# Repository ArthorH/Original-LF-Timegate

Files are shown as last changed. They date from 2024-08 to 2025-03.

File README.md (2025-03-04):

da
## Project Status: **Finished**  
**Design** ✅ — **Fabrication** ✅ — **Assembly** ✅ — **Bringup** ✅ — **Testing** ✅  
## Key technologies:
&nbsp;&nbsp;&nbsp;&nbsp; &nbsp;&nbsp;&nbsp;&nbsp;
## What is it?
LF-Timegate is a time measurement device developed to assist with Line Follower and Line Follower Drag competitions during the [XV ROBOTIC ARENA](https://roboticarena.pl/). It features circuit lap measurements and sprint measurements in one package with ±1ms accuracy.

rect22-7

### Measurement modes:



For more information, read the [setup guide](https://github.com/ArthorH/LF-Timegate-REVA/blob/main/LF-Timegate-Setup-Guide.pdf).

## What MCU does it use?
None.



To ensure reliability and simplicity, it utilizes 10 CMOS 4000 ICs to make all the magic happen.  

Also check out new drop in replacement [sensors](https://github.com/ArthorH/Simple-IR-Light-barrier) 
## Device in action:
[In this video](https://www.youtube.com/watch?v=xdkL_AgzkSc)

&nbsp;&nbsp;&nbsp;&nbsp; &nbsp;&nbsp;&nbsp;&nbsp; 
&nbsp;&nbsp;&nbsp;&nbsp; &nbsp;&nbsp;&nbsp;&nbsp; 
&nbsp;&nbsp;&nbsp;&nbsp; &nbsp;&nbsp;&nbsp;&nbsp; 
## Caution:
It is not recommended to manufacture this version (REV A) as it has 10 errors on the PCB. They are fairly simple and fixable as shown here:

#### Error in state machine 
&nbsp;&nbsp;&nbsp;&nbsp; &nbsp;&nbsp;&nbsp;&nbsp; 
&nbsp;&nbsp;&nbsp;&nbsp; &nbsp;&nbsp;&nbsp;&nbsp; 
&nbsp;&nbsp;&nbsp;&nbsp; &nbsp;&nbsp;&nbsp;&nbsp; 

## Authors
[Artem Horiunov](https://github.com/ArthorH) - schematic (state machine) and layout

[Dominik Pluta](https://github.com/Dominik-Workshop) - ir receivers and schematic

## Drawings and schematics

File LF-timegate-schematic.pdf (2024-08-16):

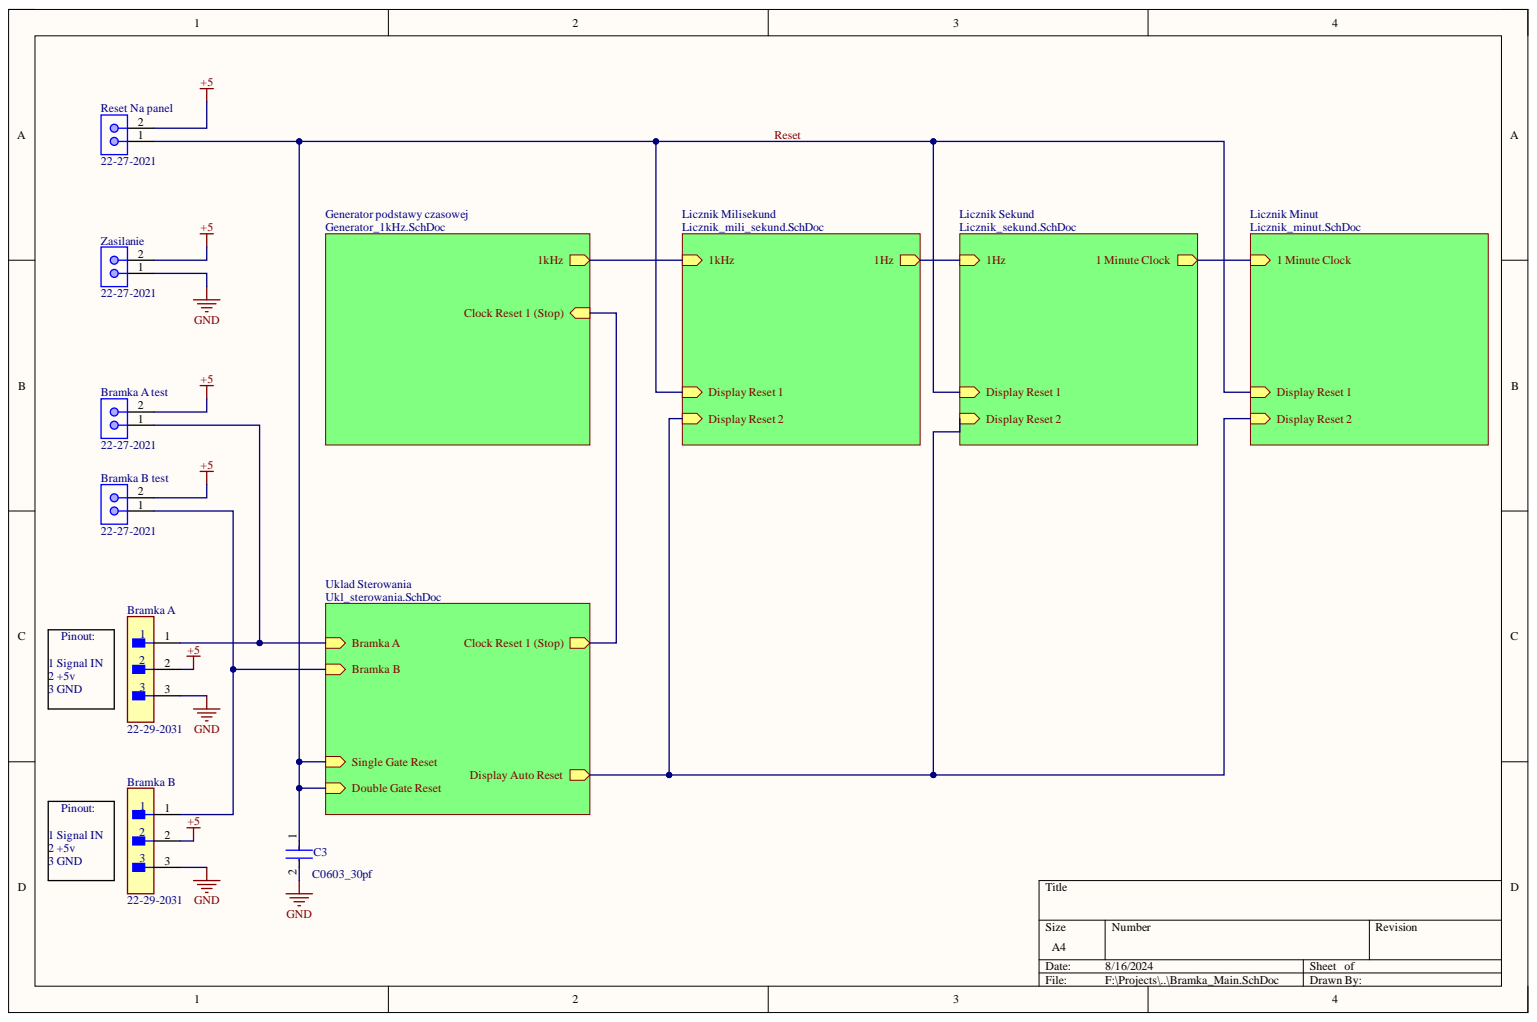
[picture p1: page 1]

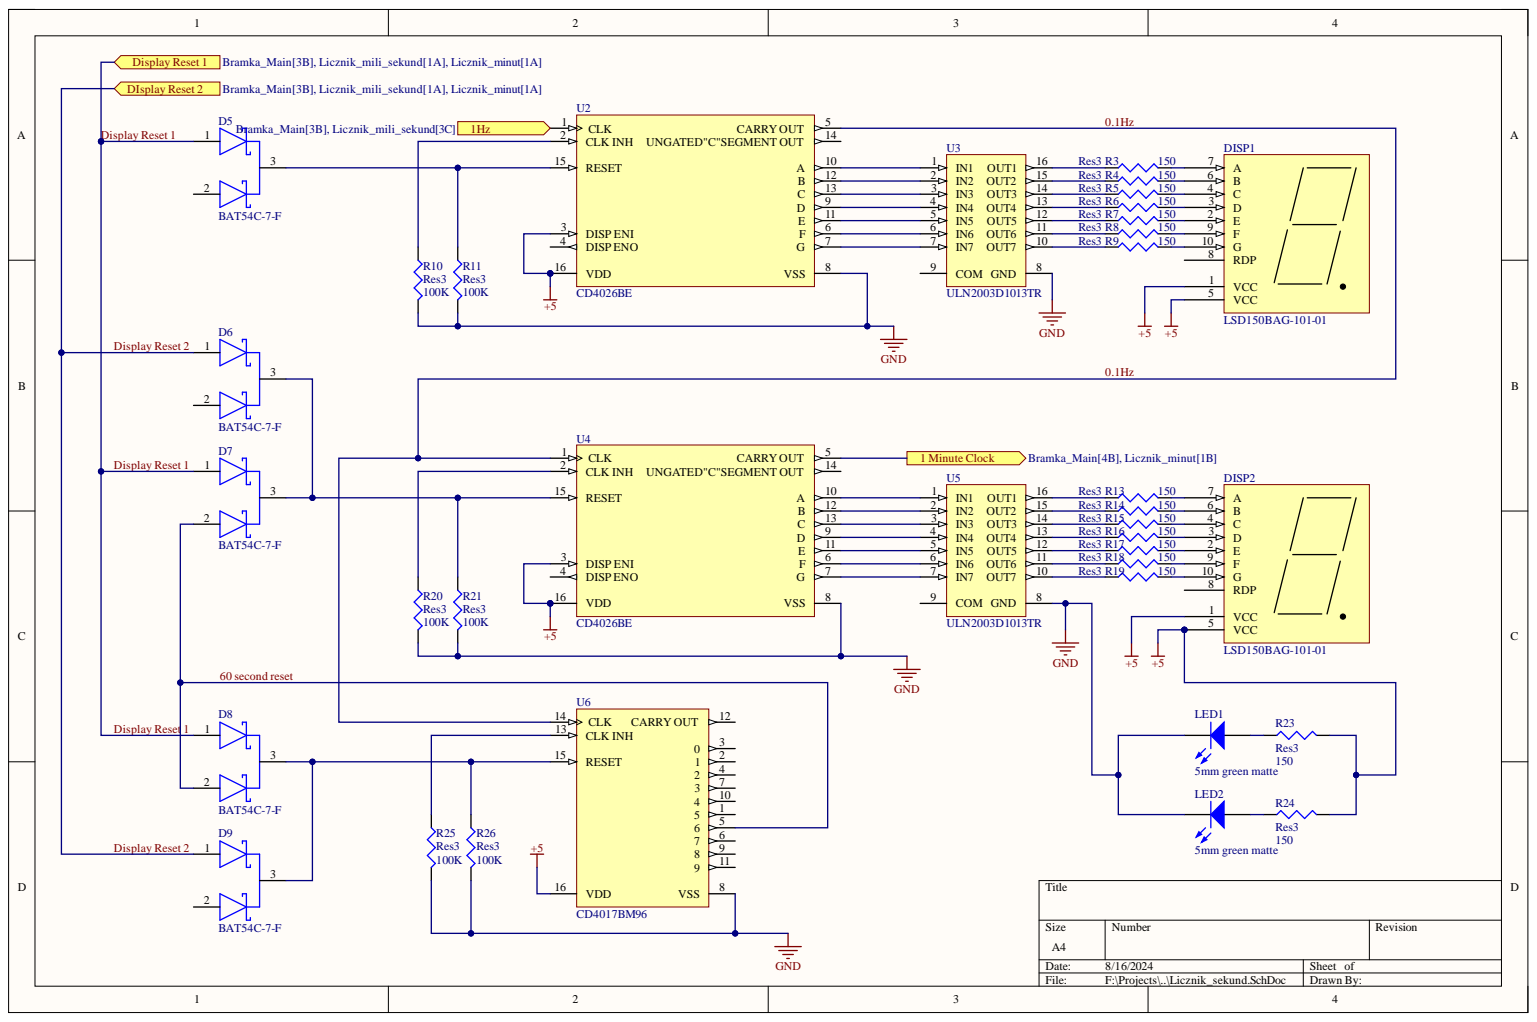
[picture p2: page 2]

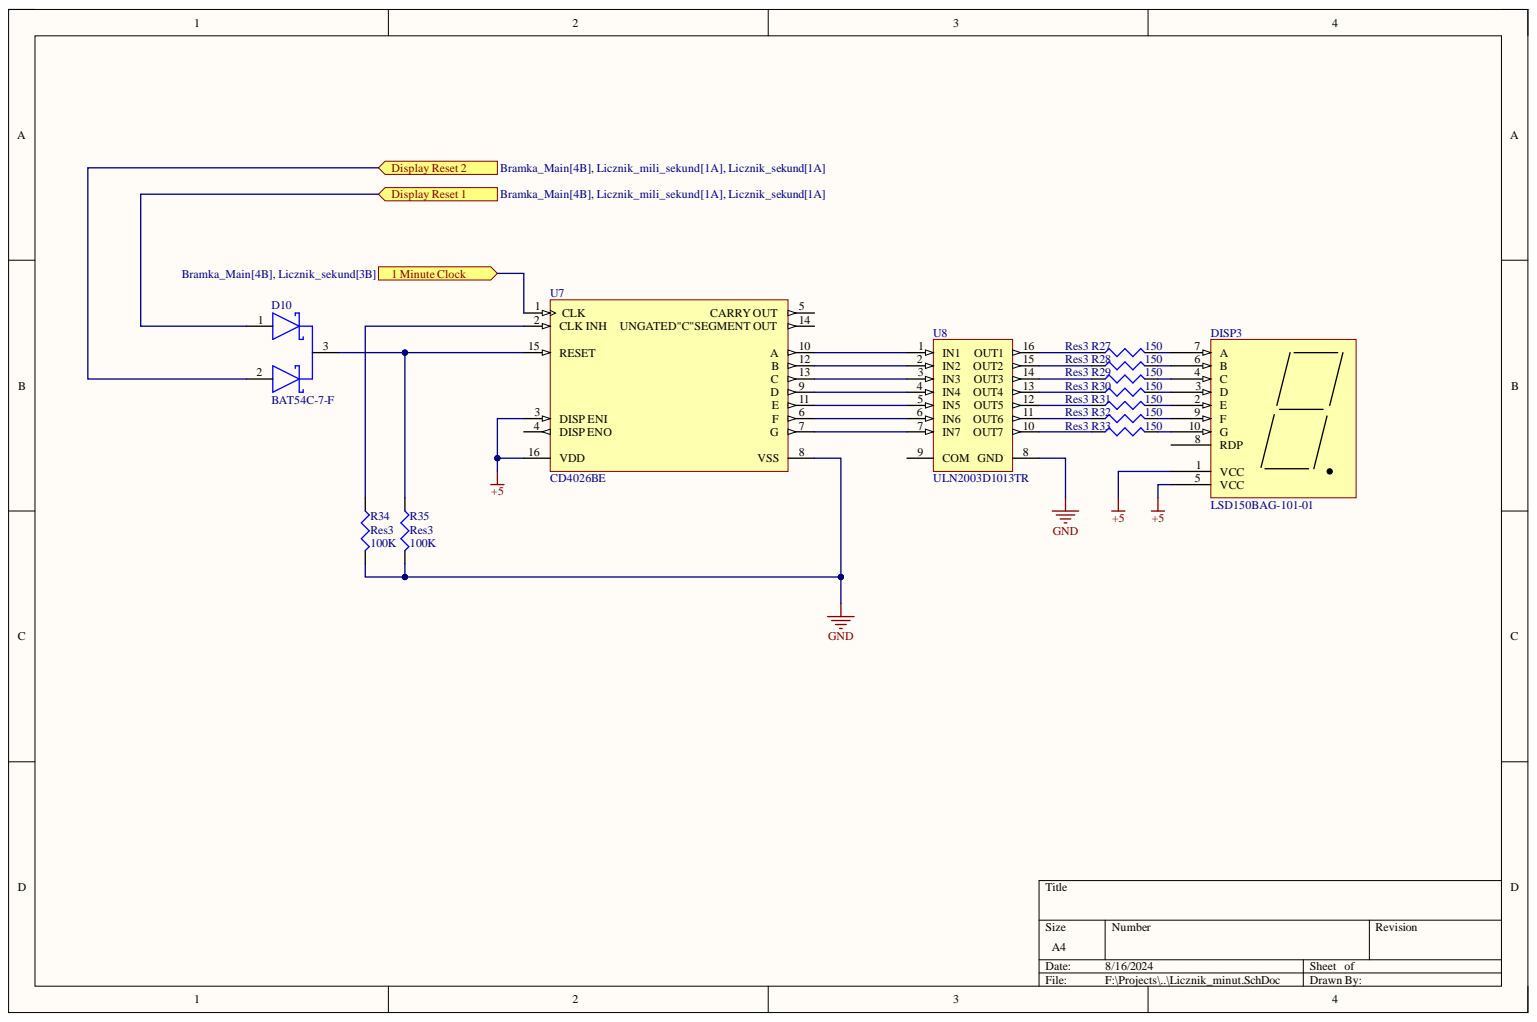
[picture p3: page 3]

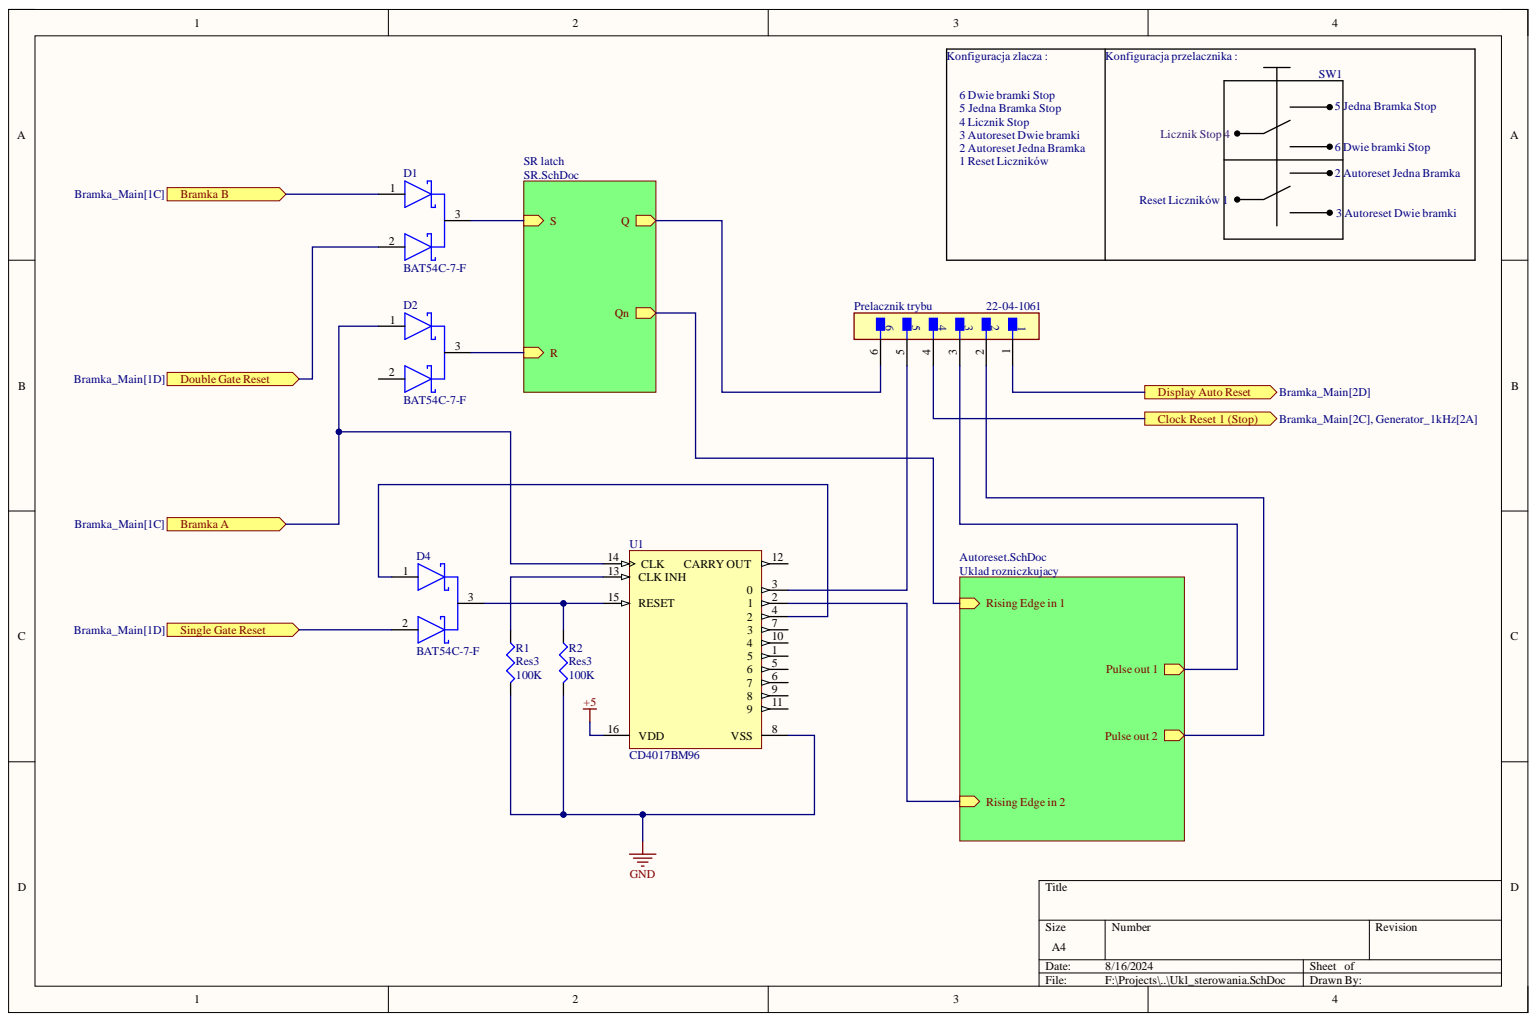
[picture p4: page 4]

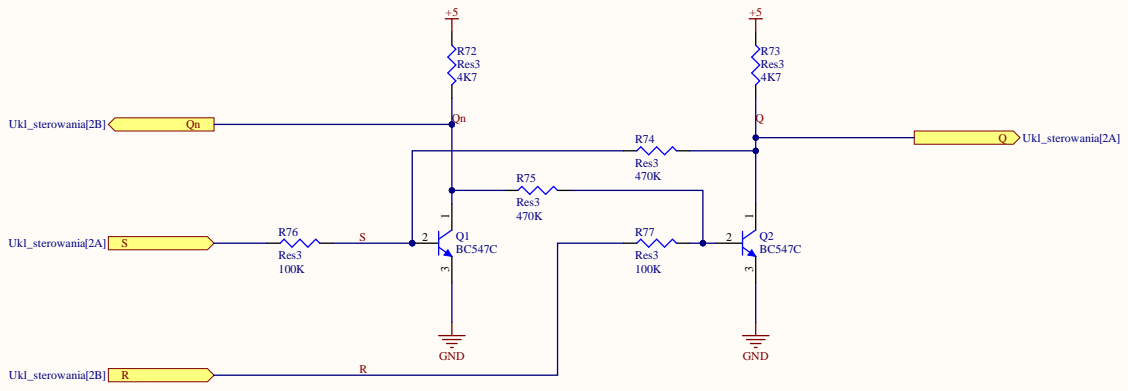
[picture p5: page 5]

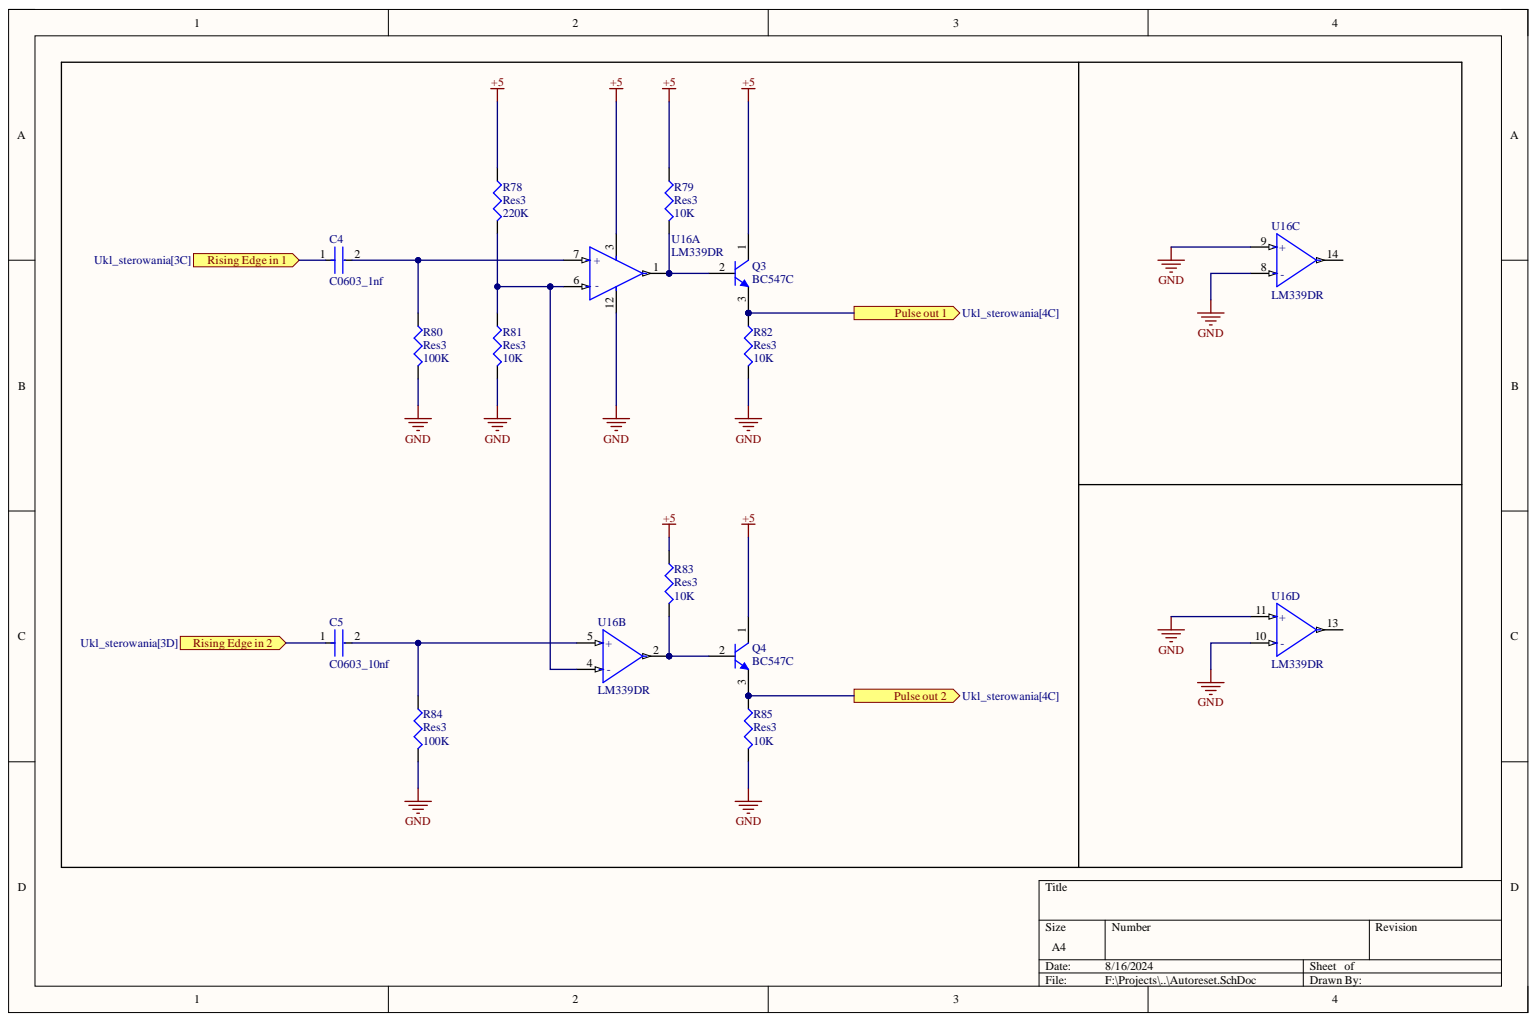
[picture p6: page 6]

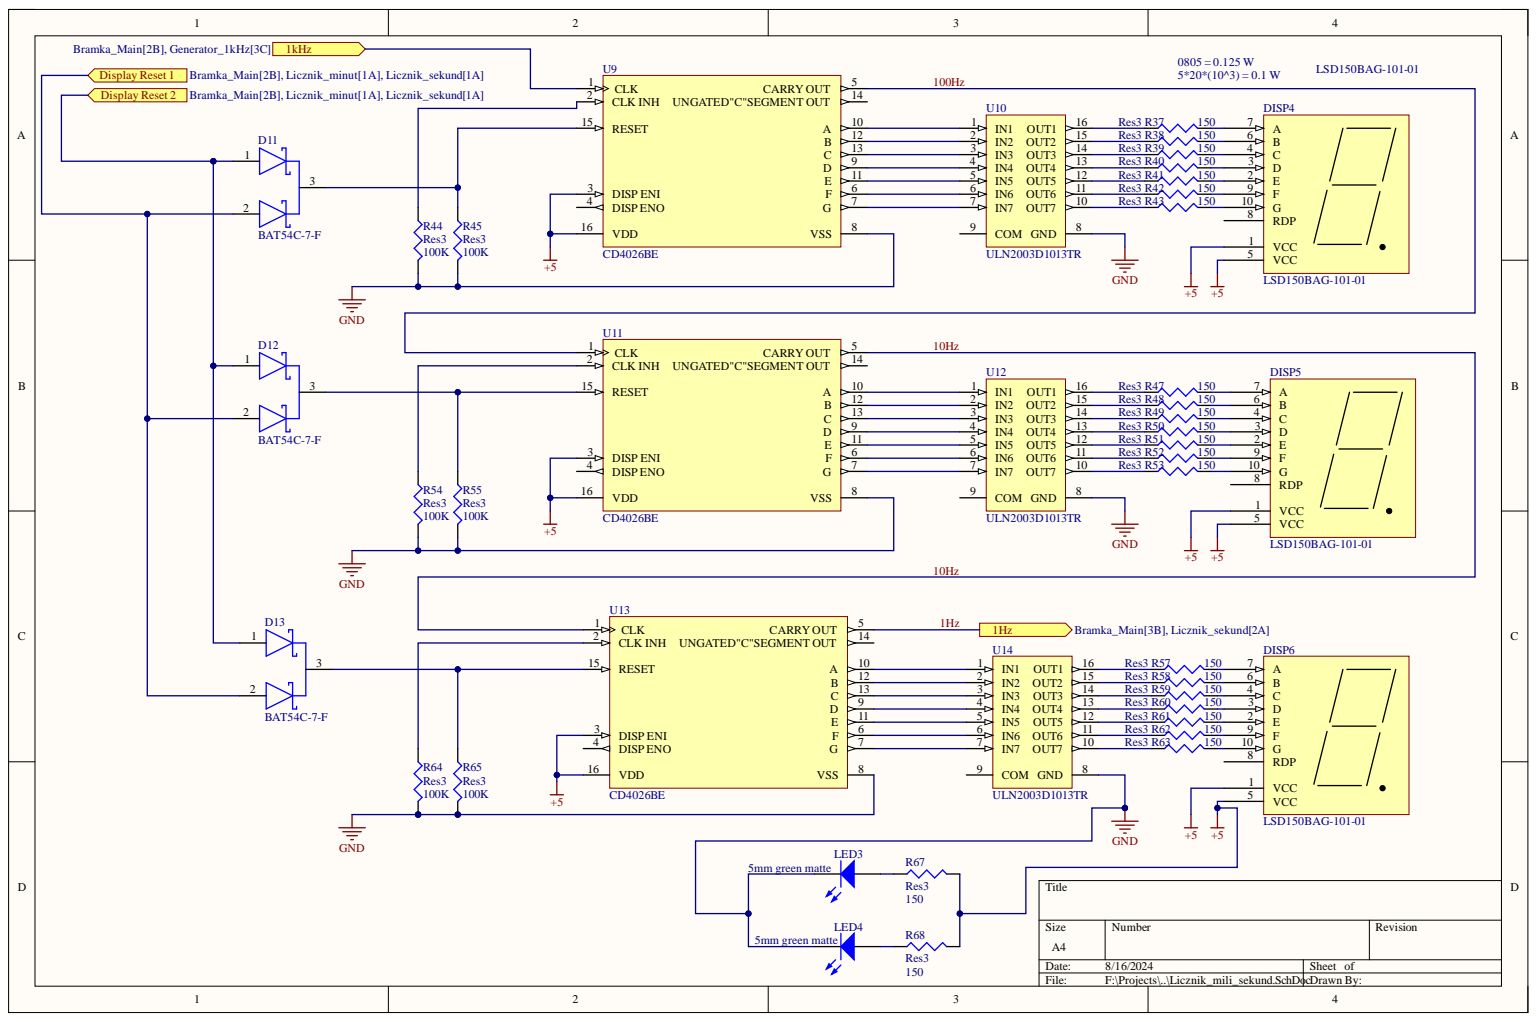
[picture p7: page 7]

VDD 16

VCC 5

VDD 16 | 10Hz

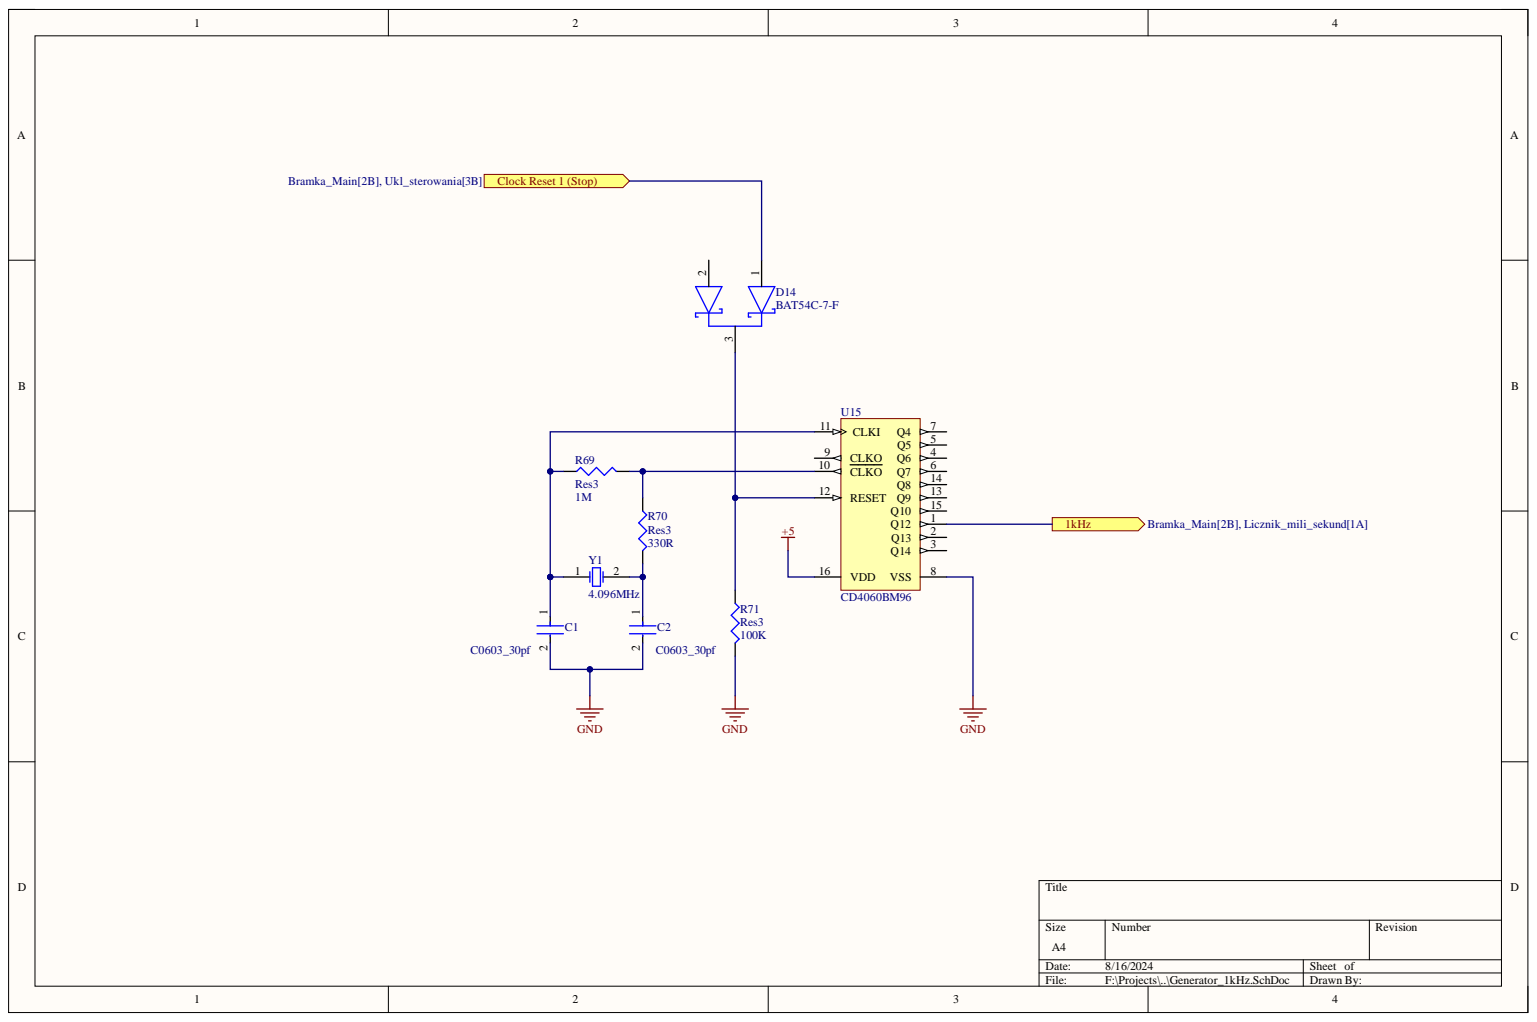
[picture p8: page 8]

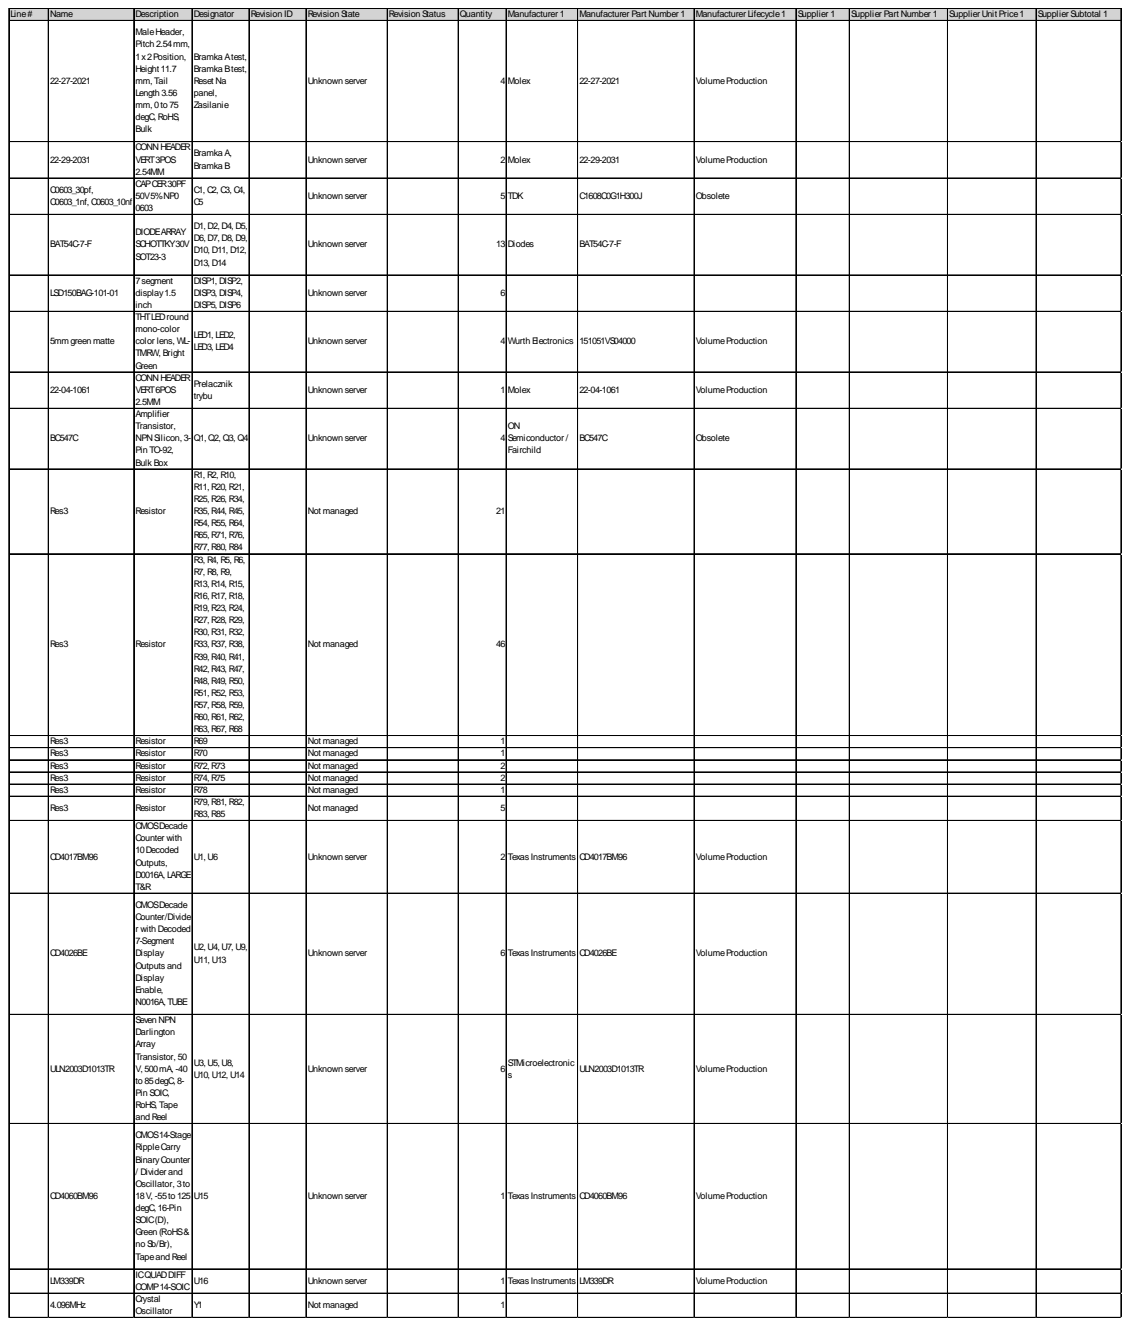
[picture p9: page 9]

Line# | Name | Description | Designator | Revision ID | Revision State | Revision Status | Quantity | Manufacturer 1 | Manufacturer Part Number 1 | Manufacturer Lifecycle1 | Supplier 1 | Supplier Part Number 1 | Supplier Unit Price1 | Supplier Subtotal 1

22-27-2021 | MaleHeader, Pitch 2.54mm, 1x2Position, Height 11.7 mm, Tail Length 3.56 mm, 0to 75 degC, RoHS, Bulk | Bramka Atest, Bramka Btest, Reset Na panel, Zasilanie | | Unknown server | | 4 Molex | | 22-27-2021 | VolumeProduction

22-29-2031 | CONN HEADER VERT3POS 2.54MM | Bramka A, Bramka B | | Unknown server | | 2 Molex | | 22-29-2031 | VolumeProduction

C0603_30pf, C0603_1nf, C0603_10nf | CAPCER30PF 50V5%NP0 0603 | C1, C2, C3, C4, C5 | | Unknown server | | 5 TDK | | C1608C0G1H300J | Obsolete

BAT54C-7-F | DIODEARRAY SCHOTTKY30V SOT23-3 | D1, D2, D4, D5, D6, D7, D8, D9, D10, D11, D12, D13, D14 | | Unknown server | | 13 Diodes | | BAT54C-7-F

LSD150BAG-101-01 | 7segment display1.5 inch | DISP1, DISP2, DISP3, DISP4, DISP5, DISP6 | | Unknown server | | 6

5mm green matte | THTLEDround mono-color color lens, WL-TMRW, Bright Green | LED1, LED2, LED3, LED4 | | Unknown server | | 4 Wurth Electronics | | 151051VS04000 | VolumeProduction

22-04-1061 | CONN HEADER VERT6POS 2.5MM | Prelacznik trybu | | Unknown server | | 1 Molex | | 22-04-1061 | VolumeProduction

BC547C | Amplifier Transistor, NPN Silicon, 3-Pin TO-92, BulkBox | Q1, Q2, Q3, Q4 | | Unknown server | | 4 | ON Semiconductor / Fairchild | BC547C | Obsolete

Res3 | Resistor | R1, R2, R10, R11, R20, R21, R25, R26, R34, R35, R44, R45, R54, R55, R64, R65, R71, R76, R77, R80, R84 | | Not managed | | 21

Res3 | Resistor | R3, R4, R5, R6, R7, R8, R9, R13, R14, R15, R16, R17, R18, R19, R23, R24, R27, R28, R29, R30, R31, R32, R33, R37, R38, R39, R40, R41, R42, R43, R47, R48, R49, R50, R51, R52, R53, R57, R58, R59, R60, R61, R62, R63, R67, R68 | | Not managed | | 46

Res3 | Resistor | R69 | | Not managed | | 1
Res3 | Resistor | R70 | | Not managed | | 1
Res3 | Resistor | R72, R73 | | Not managed | | 2
Res3 | Resistor | R74, R75 | | Not managed | | 2
Res3 | Resistor | R78 | | Not managed | | 1
Res3 | Resistor | R79, R81, R82, R83, R85 | | Not managed | | 5

CD4017BM96 | CMOSDecade Counter with 10Decoded Outputs, D0016A, LARGE T&R | U1, U6 | | Unknown server | | 2 Texas Instruments | | CD4017BM96 | VolumeProduction

CD4026BE | CMOSDecade Counter/Divide r with Decoded 7-Segment Display Outputs and Display Enable, N0016A, TUBE | U2, U4, U7, U9, U11, U13 | | Unknown server | | 6 Texas Instruments | | CD4026BE | VolumeProduction

ULN2003D1013TR | Seven NPN Darlington Array Transistor, 50 V, 500mA, -40 to 85degC, 8-Pin SOIC, RoHS, Tape and Reel | U3, U5, U8, U10, U12, U14 | | Unknown server | | 6 STMicroelectronic | s | ULN2003D1013TR | VolumeProduction

CD4060BM96 | CMOS14-Stage RippleCarry Binary Counter / Divider and Oscillator, 3to 18V, -55to 125 degC, 16-Pin SOIC(D), Green (RoHS& no Sb/Br), Tapeand Reel | U15 | | Unknown server | | 1 Texas Instruments | | CD4060BM96 | VolumeProduction

LM339DR | ICQUADDIFF COMP14-SOIC | U16 | | Unknown server | | 1 Texas Instruments | | LM339DR | VolumeProduction

4.096MHz | Crystal Oscillator | Y1 | | Not managed | | 1

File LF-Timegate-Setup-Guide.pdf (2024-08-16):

# LF TIMEGATE

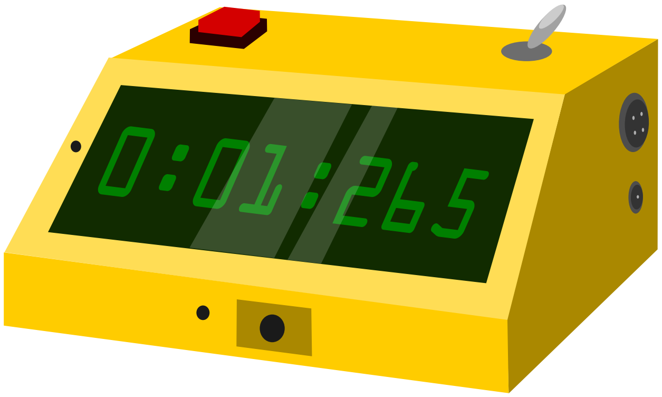
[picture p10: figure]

# QUICK SETUP GIUDE

GITHUB

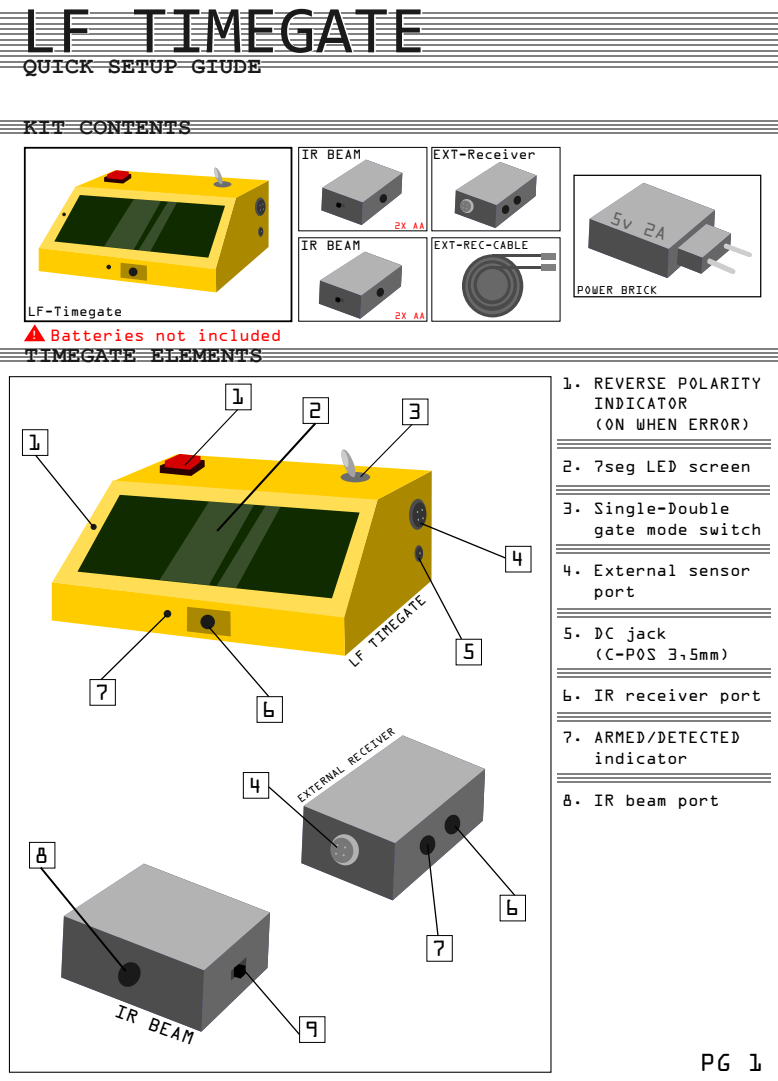
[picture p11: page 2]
KIT CONTENTS; LF TIMEGATE; IR BEAM; EXTERNAL RECEIVER; 2. 7seg LED screen; 4. External sensor port; 5. DC jack (C-POS 3,5mm); 7. ARMED/DETECTED indicator; EXT-Receiver; POWER BRICK

QUICK SETUP GIUDE

EXT-REC-CABLE

LF-Timegate
Batteries not included
TIMEGATE ELEMENTS

1. REVERSE POLARITY
INDICATOR
(ON WHEN ERROR)

3. Single-Double
gate mode switch

6. IR receiver port

8. IR beam port

1 | 2

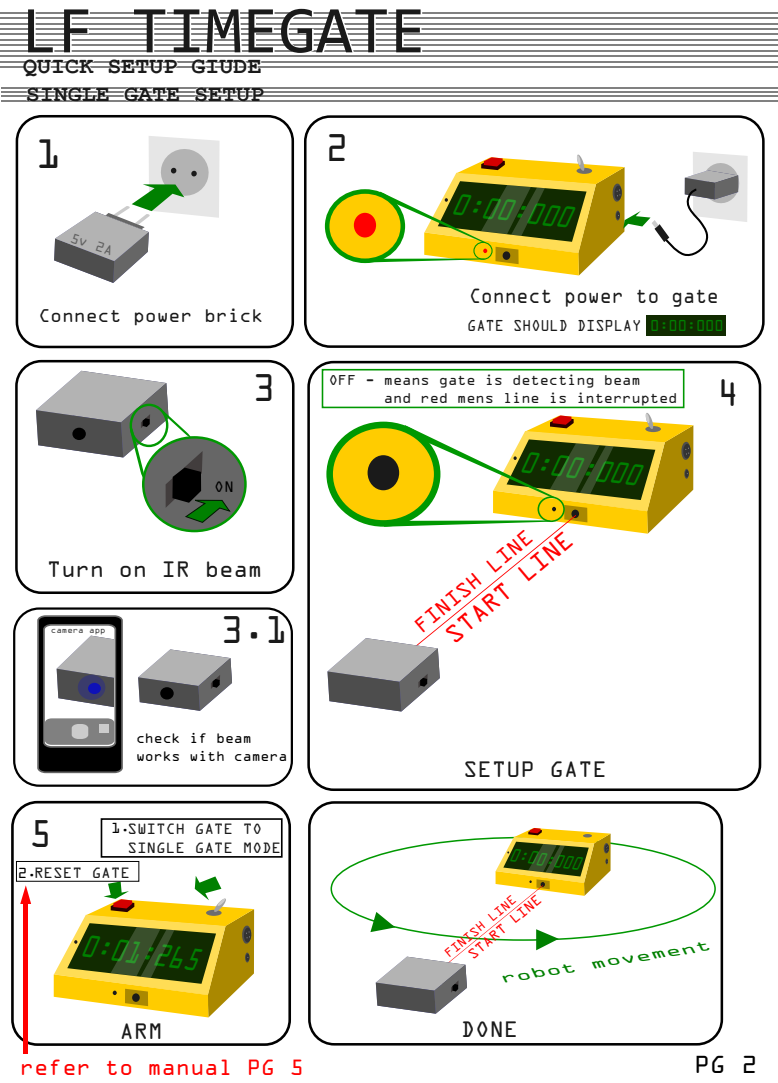
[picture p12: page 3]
SETUP GATE; ARM; DONE; GATE SHOULD DISPLAY; START LINE; camera app; 2.RESET GATE; FINISH LINE; 0:01:265 robot movement

SINGLE GATE SETUP

Connect power to gate

Connect power brick

OFF - means gate is detecting beam

and red mens line is interrupted

Turn on IR beam

check if beam
works with camera

SWITCH GATE TO
SINGLE GATE MODE

refer to manual PG 5

1 | 2

SETUP GATE; GATE SHOULD DISPLAY; START LINE; camera app; FINISH LINE

DUAL GATE SETUP

Connect power to gate

Connect power brick

Turn on IR beam 1

Connect external gate

OFF - means gate is detecting beam

and red mens line is interrupted

Turn on IR beam 2

check if beam
works with camera

6

ARM; 2.RESET GATE; DONE; START LINE; FINISH LINE; ROBOT MOVEMENT

DUAL GATE SETUP

SWITCH GATE TO
DOUBLE GATE MODE

refer to PG 5

USAGE; AUTORESET CAPABILITY; PIPELINE PIPELINE; QUEUE; REFEREE; RESET; RECORD TIME; CONTESTANT 2; AUTO RESET AUTO RESTART; SEMI AUTOMATIC; FULL AUTOMATIC

WORKS ON SINGLE AND DOUBLE

LF-TIMEGATE has built in
Autoreset capability.

This feachure allows hands free
operation during tournaments.

First run has to be done in:
SEMI AUTOMATIC
Second and following will work in:
FuLL AUTOMATIC

FIRST RUN

CONTESTANT 1
SECOND RUN
RECORD TIME OLD TIME

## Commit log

2024-08-16 REV A
    [Autoreset.SchDoc, Brameczki.PrjPcb, Bramka_Main.SchDoc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]
2024-08-16 Add cover page for duplex print
2024-08-16 Schematic PDF
